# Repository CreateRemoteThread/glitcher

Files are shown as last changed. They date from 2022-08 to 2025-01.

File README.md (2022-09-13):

# glitcher

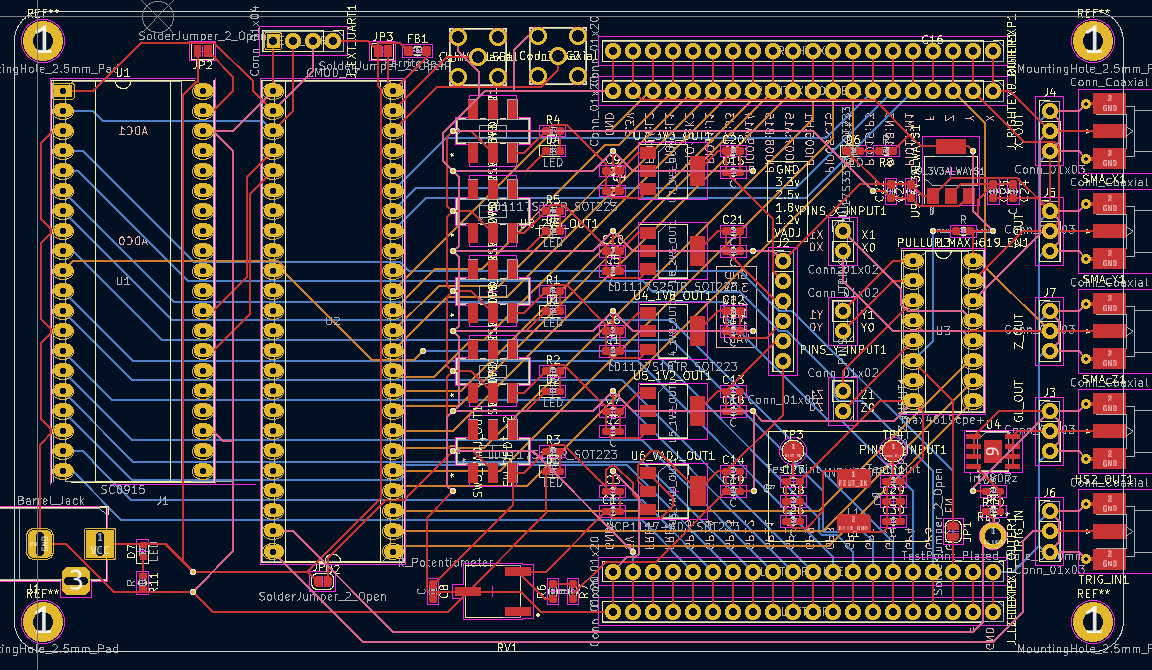
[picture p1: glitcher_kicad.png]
Glitcher Schematic


## Introduction

Glitcher is a homebrew fault injection system, built around a Pi Pico and CMOD A7, with a MAX4619 and an irf7807 providing multiplexer and crowbar mosfet style glitching respectively. Generous GPIO (FPGA + Pi Pico) + SMA outputs are available.

This project is heavily inspired by the ChipWhisperer set of products.

## Use

The Pi Pico is the simplest method of using this. Using a micro USB cable, access the MicroPython interface and use the glitcher library to control the FPGA's default firmware:

```
import glitcher

g = glitcher.Glitcher()
g.enablemux(True)                # enable max4619. crowbar always "on"
g.setmask(glitcher.SELECT_MOSFET)         # select mosfet for glitching
g.muxout(glitcher.SELECT_MUXA)            # switch x_out to x1
g.muxout(glitcher.SELECT_NONE)            # switch x_out to x0
g.rnr(delay=5,width=5)           # write delay/width, glitch output according to setmask
```

The Pi Pico uses only a serial port to talk to the FPGA at 115200bps, so you can swap it for some other uC / make a shield / whatever. Just replace self.u1 with a pyserial output if you want to use a control PC (enablemux is the only thing requiring the pi pico, just hardwire it idk).

Probably don't use g.muxout(0xF) - but do whatever you want.

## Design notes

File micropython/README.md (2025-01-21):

# Notes

Glitcher is primarily used via the MicroPython interface on the Raspberry Pi Pico. This allows for a number of things to be initialized without 

## AVR Glitcher

```import glitcher
import avr
import time

a = avr.AVRTarget()
g = glitcher.Glitcher()
g.setmask(glitcher.SELECT_MOSFET)
g.enablemux(1)
resetter = Pin(6,Pin.OUT)
resetter.value(1)

for i in range(110,130):
    if i % 5 == 0:
        print(i)
    for x in range(1,5):
        de = i
        g.setrepeat(num=2,delay=9)
        g.rnr(delay=de,width=7)
        f = a.fire()
        if f != b'62500\r\n':
            print("%d:%s" % (de,f))
            resetter.value(0)
            time.sleep(0.5)
            resetter.value(1)
            time.sleep(0.1)
            a.u1.read()
        time.sleep(0.2)```

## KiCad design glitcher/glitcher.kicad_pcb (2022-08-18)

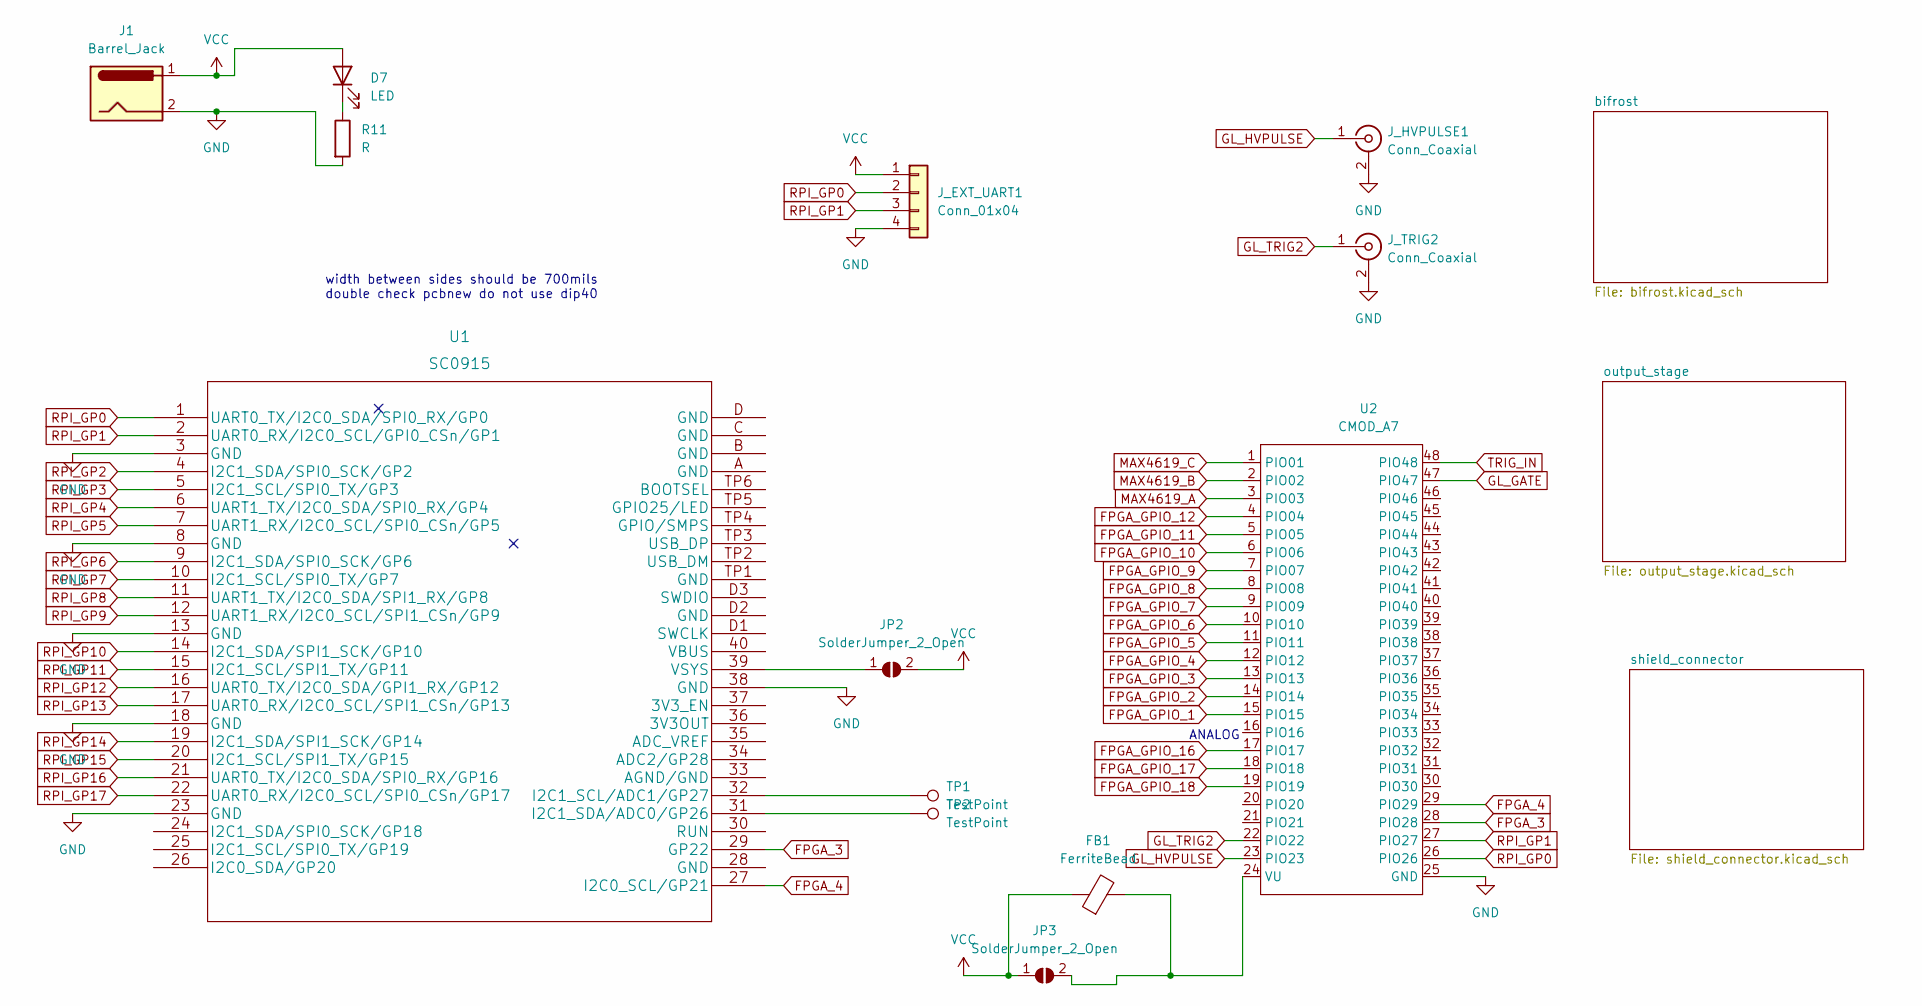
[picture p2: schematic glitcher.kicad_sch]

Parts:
D7: LED; LED_0603_1608Metric
FB1: FerriteBead; L_0805_2012Metric_Pad1.05x1.20mm_HandSolder
J1: Barrel_Jack; BarrelJack_Horizontal
JP2, JP3: SolderJumper_2_Open; SolderJumper-2_P1.3mm_Open_Pad1.0x1.5mm
J_EXT_UART1: Conn_01x04; PinHeader_1x04_P2.54mm_Vertical
J_HVPULSE1: Conn_Coaxial; RF2-04A-T-00-50-G
J_TRIG2: Conn_Coaxial; RF2-04A-T-00-50-G
R11: R; R_0603_1608Metric
TP1, TP2: TestPoint; TestPoint_Pad_D3.0mm
U1: SC0915; rpi_socket_fixed
U2: CMOD_A7; DIP-48_W15.24mm_Socket_LongPads

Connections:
FPGA_3: U1.29 (GP22), U2.28 (PIO28)
FPGA_4: U1.27 (I2C0_SCL/GP21), U2.29 (PIO29)
FPGA_GPIO_1: U2.15 (PIO15)
FPGA_GPIO_2: U2.14 (PIO14); also elsewhere on the board
FPGA_GPIO_3: U2.13 (PIO13); also elsewhere on the board
FPGA_GPIO_4: U2.12 (PIO12); also elsewhere on the board
FPGA_GPIO_5: U2.11 (PIO11); also elsewhere on the board
FPGA_GPIO_6: U2.10 (PIO10); also elsewhere on the board
FPGA_GPIO_7: U2.9 (PIO09); also elsewhere on the board
FPGA_GPIO_8: U2.8 (PIO08); also elsewhere on the board
FPGA_GPIO_9: U2.7 (PIO07); also elsewhere on the board
FPGA_GPIO_10: U2.6 (PIO06); also elsewhere on the board
FPGA_GPIO_11: U2.5 (PIO05); also elsewhere on the board
FPGA_GPIO_12: U2.4 (PIO04); also elsewhere on the board
FPGA_GPIO_16: U2.17 (PIO17); also elsewhere on the board
FPGA_GPIO_17: U2.18 (PIO18); also elsewhere on the board
FPGA_GPIO_18: U2.19 (PIO19); also elsewhere on the board
GL_GATE: U2.47 (PIO47); also elsewhere on the board
GL_HVPULSE: J_HVPULSE1.1 (In), U2.23 (PIO23)
GL_TRIG2: J_TRIG2.1 (In), U2.22 (PIO22)
GND: J1.2, J_EXT_UART1.4, J_HVPULSE1.2 (Ext), J_HVPULSE1.3, J_HVPULSE1.4, J_HVPULSE1.5, J_TRIG2.2 (Ext), J_TRIG2.3, J_TRIG2.4, J_TRIG2.5, R11.2, U1.3 (GND), U1.8 (GND), U1.13 (GND), U1.18 (GND), U1.23 (GND), U1.38 (GND), U2.25 (GND); also elsewhere on the board
MAX4619_A: U2.3 (PIO03); also elsewhere on the board
MAX4619_B: U2.2 (PIO02); also elsewhere on the board
MAX4619_C: U2.1 (PIO01); also elsewhere on the board
unnamed: D7.1 (K), R11.1
unnamed: FB1.2, JP3.2 (B), U2.24 (VU)
unnamed: JP2.1 (A), U1.39 (VSYS)
unnamed: TP1.1, U1.32 (I2C1_SCL/ADC1/GP27)
unnamed: TP2.1, U1.31 (I2C1_SDA/ADC0/GP26)
RPI_GP0: J_EXT_UART1.2, U1.1 (UART0_TX/I2C0_SDA/SPI0_RX/GP0), U2.26 (PIO26)
RPI_GP1: J_EXT_UART1.3, U1.2 (UART0_RX/I2C0_SCL/GPI0_CSn/GP1), U2.27 (PIO27)
RPI_GP2: U1.4 (I2C1_SDA/SPI0_SCK/GP2); also elsewhere on the board
RPI_GP3: U1.5 (I2C1_SCL/SPI0_TX/GP3); also elsewhere on the board
RPI_GP4: U1.6 (UART1_TX/I2C0_SDA/SPI0_RX/GP4); also elsewhere on the board
RPI_GP5: U1.7 (UART1_RX/I2C0_SCL/SPI0_CSn/GP5); also elsewhere on the board
RPI_GP6: U1.9 (I2C1_SDA/SPI0_SCK/GP6); also elsewhere on the board
RPI_GP7: U1.10 (I2C1_SCL/SPI0_TX/GP7); also elsewhere on the board
RPI_GP8: U1.11 (UART1_TX/I2C0_SDA/SPI1_RX/GP8); also elsewhere on the board
RPI_GP9: U1.12 (UART1_RX/I2C0_SCL/SPI1_CSn/GP9); also elsewhere on the board
RPI_GP10: U1.14 (I2C1_SDA/SPI1_SCK/GP10); also elsewhere on the board
RPI_GP11: U1.15 (I2C1_SCL/SPI1_TX/GP11); also elsewhere on the board
RPI_GP12: U1.16 (UART0_TX/I2C0_SDA/GPI1_RX/GP12); also elsewhere on the board
RPI_GP13: U1.17 (UART0_RX/I2C0_SCL/SPI1_CSn/GP13); also elsewhere on the board
RPI_GP14: U1.19 (I2C1_SDA/SPI1_SCK/GP14); also elsewhere on the board
RPI_GP15: U1.20 (I2C1_SCL/SPI1_TX/GP15); also elsewhere on the board
RPI_GP16: U1.21 (UART0_TX/I2C0_SDA/SPI0_RX/GP16)
RPI_GP17: U1.22 (UART0_RX/I2C0_SCL/SPI0_CSn/GP17)
TRIG_IN: U2.48 (PIO48); also elsewhere on the board
VCC: D7.2 (A), FB1.1, J1.1, JP2.2 (B), JP3.1 (A), J_EXT_UART1.1; also elsewhere on the board

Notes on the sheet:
width between sides should be 700mils double check pcbnew do not use dip40
ANALOG

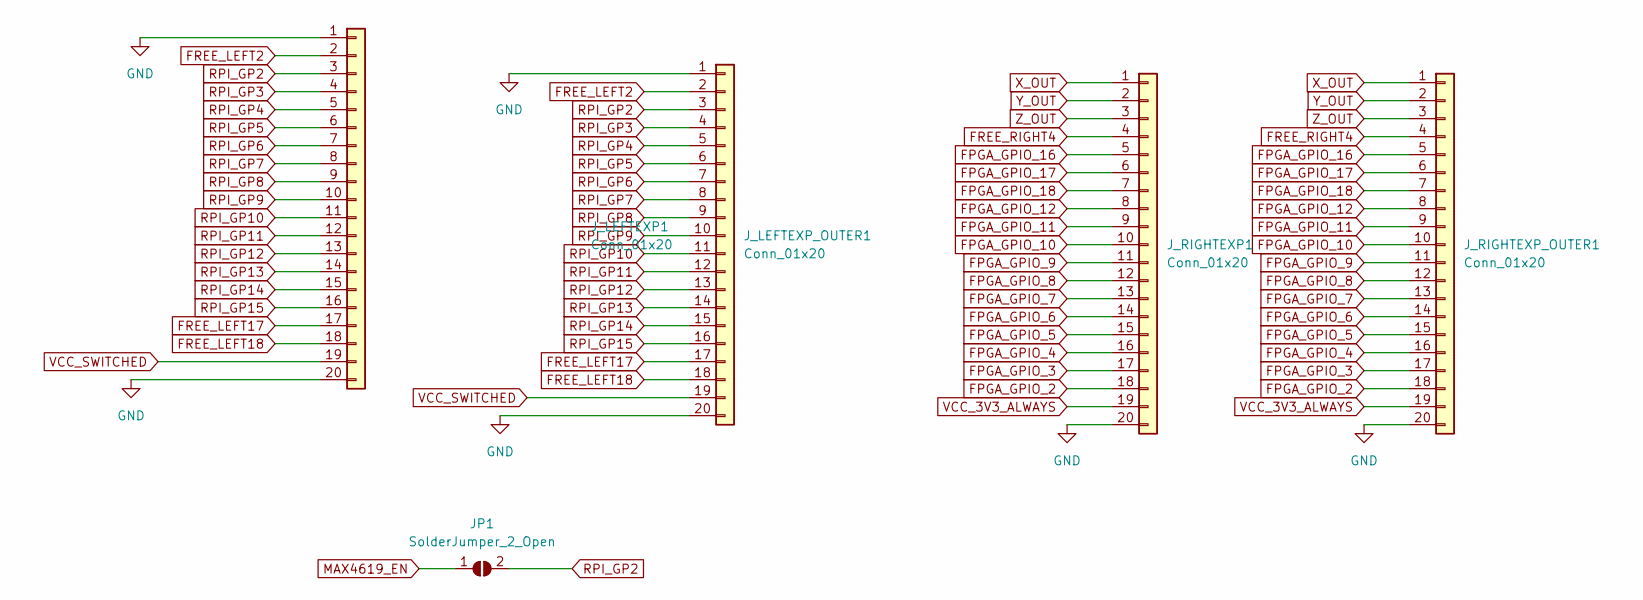
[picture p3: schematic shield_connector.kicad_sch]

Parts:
JP1: SolderJumper_2_Open; SolderJumper-2_P1.3mm_Open_RoundedPad1.0x1.5mm
J_LEFTEXP1: Conn_01x20; PinHeader_1x20_P2.54mm_Vertical
J_LEFTEXP_OUTER1: Conn_01x20; PinHeader_1x20_P2.54mm_Vertical
J_RIGHTEXP1: Conn_01x20; PinHeader_1x20_P2.54mm_Vertical
J_RIGHTEXP_OUTER1: Conn_01x20; PinHeader_1x20_P2.54mm_Vertical

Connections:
FPGA_GPIO_2: J_RIGHTEXP1.18, J_RIGHTEXP_OUTER1.18; also elsewhere on the board
FPGA_GPIO_3: J_RIGHTEXP1.17, J_RIGHTEXP_OUTER1.17; also elsewhere on the board
FPGA_GPIO_4: J_RIGHTEXP1.16, J_RIGHTEXP_OUTER1.16; also elsewhere on the board
FPGA_GPIO_5: J_RIGHTEXP1.15, J_RIGHTEXP_OUTER1.15; also elsewhere on the board
FPGA_GPIO_6: J_RIGHTEXP1.14, J_RIGHTEXP_OUTER1.14; also elsewhere on the board
FPGA_GPIO_7: J_RIGHTEXP1.13, J_RIGHTEXP_OUTER1.13; also elsewhere on the board
FPGA_GPIO_8: J_RIGHTEXP1.12, J_RIGHTEXP_OUTER1.12; also elsewhere on the board
FPGA_GPIO_9: J_RIGHTEXP1.11, J_RIGHTEXP_OUTER1.11; also elsewhere on the board
FPGA_GPIO_10: J_RIGHTEXP1.10, J_RIGHTEXP_OUTER1.10; also elsewhere on the board
FPGA_GPIO_11: J_RIGHTEXP1.9, J_RIGHTEXP_OUTER1.9; also elsewhere on the board
FPGA_GPIO_12: J_RIGHTEXP1.8, J_RIGHTEXP_OUTER1.8; also elsewhere on the board
FPGA_GPIO_16: J_RIGHTEXP1.5, J_RIGHTEXP_OUTER1.5; also elsewhere on the board
FPGA_GPIO_17: J_RIGHTEXP1.6, J_RIGHTEXP_OUTER1.6; also elsewhere on the board
FPGA_GPIO_18: J_RIGHTEXP1.7, J_RIGHTEXP_OUTER1.7; also elsewhere on the board
FREE_LEFT2: J_LEFTEXP1.2, J_LEFTEXP_OUTER1.2
FREE_LEFT17: J_LEFTEXP1.17, J_LEFTEXP_OUTER1.17
FREE_LEFT18: J_LEFTEXP1.18, J_LEFTEXP_OUTER1.18
FREE_RIGHT4: J_RIGHTEXP1.4, J_RIGHTEXP_OUTER1.4
GND: J_LEFTEXP1.1, J_LEFTEXP1.20, J_LEFTEXP_OUTER1.1, J_LEFTEXP_OUTER1.20, J_RIGHTEXP1.20, J_RIGHTEXP_OUTER1.20; also elsewhere on the board
MAX4619_EN: JP1.1 (A); also elsewhere on the board
RPI_GP2: JP1.2 (B), J_LEFTEXP1.3, J_LEFTEXP_OUTER1.3; also elsewhere on the board
RPI_GP3: J_LEFTEXP1.4, J_LEFTEXP_OUTER1.4; also elsewhere on the board
RPI_GP4: J_LEFTEXP1.5, J_LEFTEXP_OUTER1.5; also elsewhere on the board
RPI_GP5: J_LEFTEXP1.6, J_LEFTEXP_OUTER1.6; also elsewhere on the board
RPI_GP6: J_LEFTEXP1.7, J_LEFTEXP_OUTER1.7; also elsewhere on the board
RPI_GP7: J_LEFTEXP1.8, J_LEFTEXP_OUTER1.8; also elsewhere on the board
RPI_GP8: J_LEFTEXP1.9, J_LEFTEXP_OUTER1.9; also elsewhere on the board
RPI_GP9: J_LEFTEXP1.10, J_LEFTEXP_OUTER1.10; also elsewhere on the board
RPI_GP10: J_LEFTEXP1.11, J_LEFTEXP_OUTER1.11; also elsewhere on the board
RPI_GP11: J_LEFTEXP1.12, J_LEFTEXP_OUTER1.12; also elsewhere on the board
RPI_GP12: J_LEFTEXP1.13, J_LEFTEXP_OUTER1.13; also elsewhere on the board
RPI_GP13: J_LEFTEXP1.14, J_LEFTEXP_OUTER1.14; also elsewhere on the board
RPI_GP14: J_LEFTEXP1.15, J_LEFTEXP_OUTER1.15; also elsewhere on the board
RPI_GP15: J_LEFTEXP1.16, J_LEFTEXP_OUTER1.16; also elsewhere on the board
VCC_3V3_ALWAYS: J_RIGHTEXP1.19, J_RIGHTEXP_OUTER1.19; also elsewhere on the board
VCC_SWITCHED: J_LEFTEXP1.19, J_LEFTEXP_OUTER1.19; also elsewhere on the board
X_OUT: J_RIGHTEXP1.1, J_RIGHTEXP_OUTER1.1; also elsewhere on the board
Y_OUT: J_RIGHTEXP1.2, J_RIGHTEXP_OUTER1.2; also elsewhere on the board
Z_OUT: J_RIGHTEXP1.3, J_RIGHTEXP_OUTER1.3; also elsewhere on the board

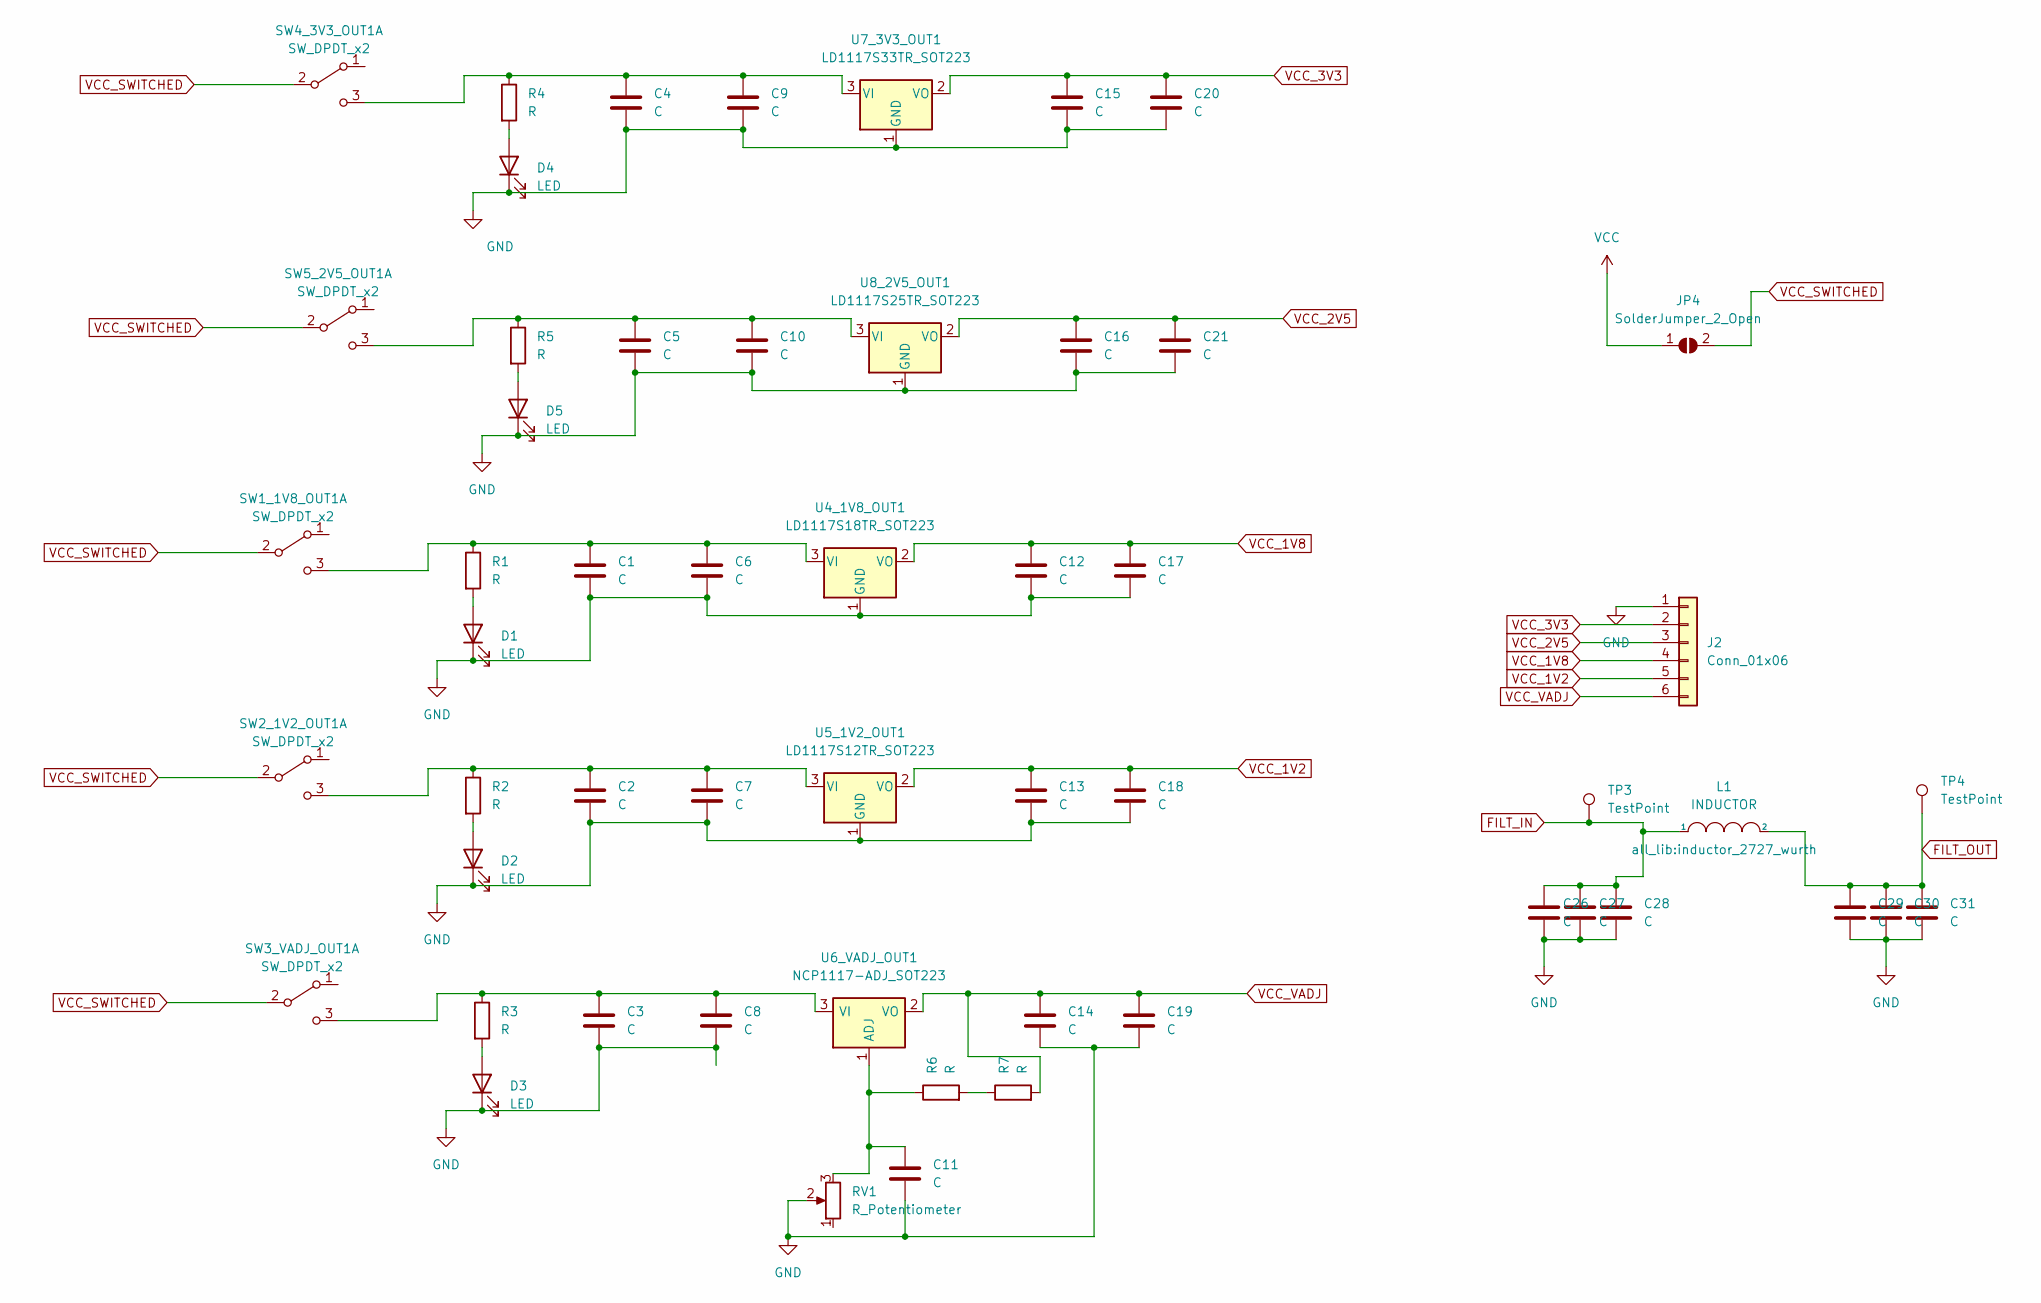
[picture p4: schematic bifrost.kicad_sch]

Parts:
C1, C2, C3, C4, C5, C6, C7, C8, C9, C10, C11, C12, C13, C14, C15, C16, C17, C18, C19, C20, C21, C26, C27, C28, C29, C30, C31: C; C_0603_1608Metric_Pad1.08x0.95mm_HandSolder
D1, D2, D3, D4, D5: LED; LED_0603_1608Metric_Pad1.05x0.95mm_HandSolder
J2: Conn_01x06; PinHeader_1x06_P2.54mm_Vertical
JP4: SolderJumper_2_Open; SolderJumper-2_P1.3mm_Open_RoundedPad1.0x1.5mm
L1: INDUCTOR; inductor_2727_wurth
R1, R2, R3, R4, R5, R6, R7: R; R_0603_1608Metric_Pad0.98x0.95mm_HandSolder
RV1: R_Potentiometer; TRIM_3361P-1-501GLF
SW1_1V8_OUT1, SW2_1V2_OUT1, SW3_VADJ_OUT1, SW4_3V3_OUT1, SW5_2V5_OUT1: SW_DPDT_x2; JS202011SCQN
TP3, TP4: TestPoint; TestPoint_Pad_D2.5mm
U4_1V8_OUT1: LD1117S18TR_SOT223; SOT-223-3_TabPin2
U5_1V2_OUT1: LD1117S12TR_SOT223; SOT-223-3_TabPin2
U6_VADJ_OUT1: NCP1117-ADJ_SOT223; SOT-223-3_TabPin2
U7_3V3_OUT1: LD1117S33TR_SOT223; SOT-223-3_TabPin2
U8_2V5_OUT1: LD1117S25TR_SOT223; SOT-223-3_TabPin2

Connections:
FILT_IN: C26.1, C27.1, C28.1, L1.1, TP3.1
FILT_OUT: C29.1, C30.1, C31.1, L1.2, TP4.1
GND: C1.2, C2.2, C3.2, C4.2, C5.2, C6.2, C7.2, C8.2, C9.2, C10.2, C11.2, C12.2, C13.2, C14.2, C15.2, C16.2, C17.2, C18.2, C19.2, C20.2, C21.2, C26.2, C27.2, C28.2, C29.2, C30.2, C31.2, D1.1 (K), D2.1 (K), D3.1 (K), D4.1 (K), D5.1 (K), J2.1, RV1.2, U4_1V8_OUT1.1 (GND), U5_1V2_OUT1.1 (GND), U7_3V3_OUT1.1 (GND), U8_2V5_OUT1.1 (GND); also elsewhere on the board
unnamed: C1.1, C6.1, R1.1, SW1_1V8_OUT1.3 (C), U4_1V8_OUT1.3 (VI)
unnamed: C2.1, C7.1, R2.1, SW2_1V2_OUT1.3 (C), U5_1V2_OUT1.3 (VI)
unnamed: C3.1, C8.1, R3.1, SW3_VADJ_OUT1.3 (C), U6_VADJ_OUT1.3 (VI)
unnamed: C4.1, C9.1, R4.1, SW4_3V3_OUT1.3 (C), U7_3V3_OUT1.3 (VI)
unnamed: C5.1, C10.1, R5.1, SW5_2V5_OUT1.3 (C), U8_2V5_OUT1.3 (VI)
unnamed: C11.1, R6.1, RV1.3, U6_VADJ_OUT1.1 (ADJ)
unnamed: D1.2 (A), R1.2
unnamed: D2.2 (A), R2.2
unnamed: D3.2 (A), R3.2
unnamed: D4.2 (A), R4.2
unnamed: D5.2 (A), R5.2
unnamed: R6.2, R7.1
VCC: JP4.1 (A); also elsewhere on the board
VCC_1V2: C13.1, C18.1, J2.5, U5_1V2_OUT1.2 (VO)
VCC_1V8: C12.1, C17.1, J2.4, U4_1V8_OUT1.2 (VO)
VCC_2V5: C16.1, C21.1, J2.3, U8_2V5_OUT1.2 (VO)
VCC_3V3: C15.1, C20.1, J2.2, U7_3V3_OUT1.2 (VO)
VCC_SWITCHED: JP4.2 (B), SW1_1V8_OUT1.2 (B), SW2_1V2_OUT1.2 (B), SW3_VADJ_OUT1.2 (B), SW4_3V3_OUT1.2 (B), SW5_2V5_OUT1.2 (B); also elsewhere on the board
VCC_VADJ: C14.1, C19.1, J2.6, R7.2, U6_VADJ_OUT1.2 (VO)

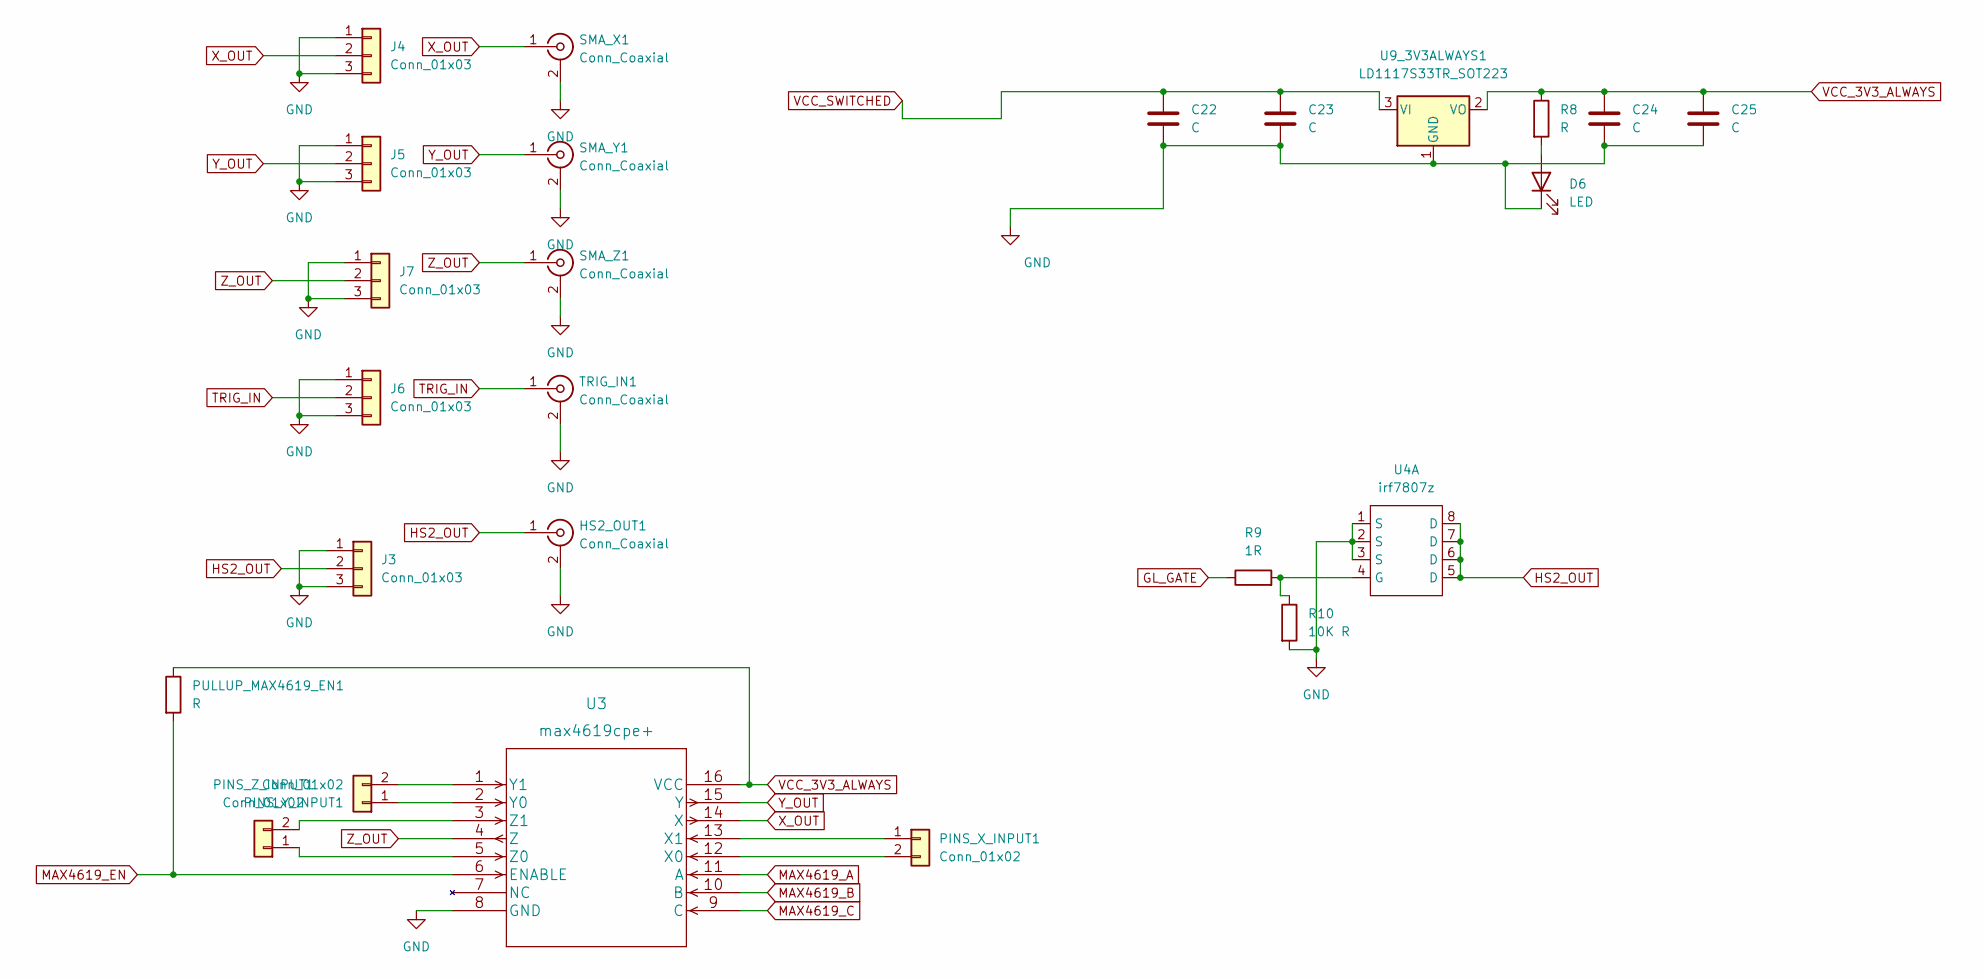
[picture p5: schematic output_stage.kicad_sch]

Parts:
C22, C23, C24, C25: C; C_0603_1608Metric_Pad1.08x0.95mm_HandSolder
D6: LED; LED_0603_1608Metric_Pad1.05x0.95mm_HandSolder
HS2_OUT1: Conn_Coaxial; SMA_Molex_73251-2120_EdgeMount_Horizontal
J3, J4, J5, J6, J7: Conn_01x03; PinHeader_1x03_P2.54mm_Vertical
PINS_X_INPUT1: Conn_01x02; PinHeader_1x02_P2.54mm_Vertical
PINS_Y_INPUT1: Conn_01x02; PinHeader_1x02_P2.54mm_Vertical
PINS_Z_INPUT1: Conn_01x02; PinHeader_1x02_P2.54mm_Vertical
PULLUP_MAX4619_EN1: R; R_0603_1608Metric_Pad0.98x0.95mm_HandSolder
R8: R; R_0603_1608Metric_Pad0.98x0.95mm_HandSolder
R9: 1R; R_0603_1608Metric_Pad0.98x0.95mm_HandSolder
R10: 10K R; R_0603_1608Metric_Pad0.98x0.95mm_HandSolder
SMA_X1: Conn_Coaxial; SMA_Molex_73251-2120_EdgeMount_Horizontal
SMA_Y1: Conn_Coaxial; SMA_Molex_73251-2120_EdgeMount_Horizontal
SMA_Z1: Conn_Coaxial; SMA_Molex_73251-2120_EdgeMount_Horizontal
TRIG_IN1: Conn_Coaxial; SMA_Molex_73251-2120_EdgeMount_Horizontal
U3: max4619cpe+; DIP-16_W7.62mm_Socket_LongPads
U4: irf7807z; SOIC-8-1EP_3.9x4.9mm_P1.27mm_EP2.29x3mm
U9_3V3ALWAYS1: LD1117S33TR_SOT223; SOT-223-3_TabPin2

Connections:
GL_GATE: R9.1; also elsewhere on the board
GND: C22.2, C23.2, C24.2, C25.2, D6.1 (K), HS2_OUT1.2 (Ext), J3.1, J3.3, J4.1, J4.3, J5.1, J5.3, J6.1, J6.3, J7.1, J7.3, R10.2, SMA_X1.2 (Ext), SMA_Y1.2 (Ext), SMA_Z1.2 (Ext), TRIG_IN1.2 (Ext), U3.8 (GND), U4.1 (S), U4.2 (S), U4.3 (S), U9_3V3ALWAYS1.1 (GND); also elsewhere on the board
HS2_OUT: HS2_OUT1.1 (In), J3.2, U4.5 (D), U4.6 (D), U4.7 (D), U4.8 (D)
MAX4619_A: U3.11 (A); also elsewhere on the board
MAX4619_B: U3.10 (B); also elsewhere on the board
MAX4619_C: U3.9 (C); also elsewhere on the board
MAX4619_EN: PULLUP_MAX4619_EN1.2, U3.6 (ENABLE); also elsewhere on the board
unnamed: D6.2 (A), R8.2
unnamed: PINS_X_INPUT1.1, U3.13 (X1)
unnamed: PINS_X_INPUT1.2, U3.12 (X0)
unnamed: PINS_Y_INPUT1.1, U3.2 (Y0)
unnamed: PINS_Y_INPUT1.2, U3.1 (Y1)
unnamed: PINS_Z_INPUT1.1, U3.5 (Z0)
unnamed: PINS_Z_INPUT1.2, U3.3 (Z1)
unnamed: R9.2, R10.1, U4.4 (G)
TRIG_IN: J6.2, TRIG_IN1.1 (In); also elsewhere on the board
VCC_3V3_ALWAYS: C24.1, C25.1, PULLUP_MAX4619_EN1.1, R8.1, U3.16 (VCC), U9_3V3ALWAYS1.2 (VO); also elsewhere on the board
VCC_SWITCHED: C22.1, C23.1, U9_3V3ALWAYS1.3 (VI); also elsewhere on the board
X_OUT: J4.2, SMA_X1.1 (In), U3.14 (X); also elsewhere on the board
Y_OUT: J5.2, SMA_Y1.1 (In), U3.15 (Y); also elsewhere on the board
Z_OUT: J7.2, SMA_Z1.1 (In), U3.4 (Z); also elsewhere on the board

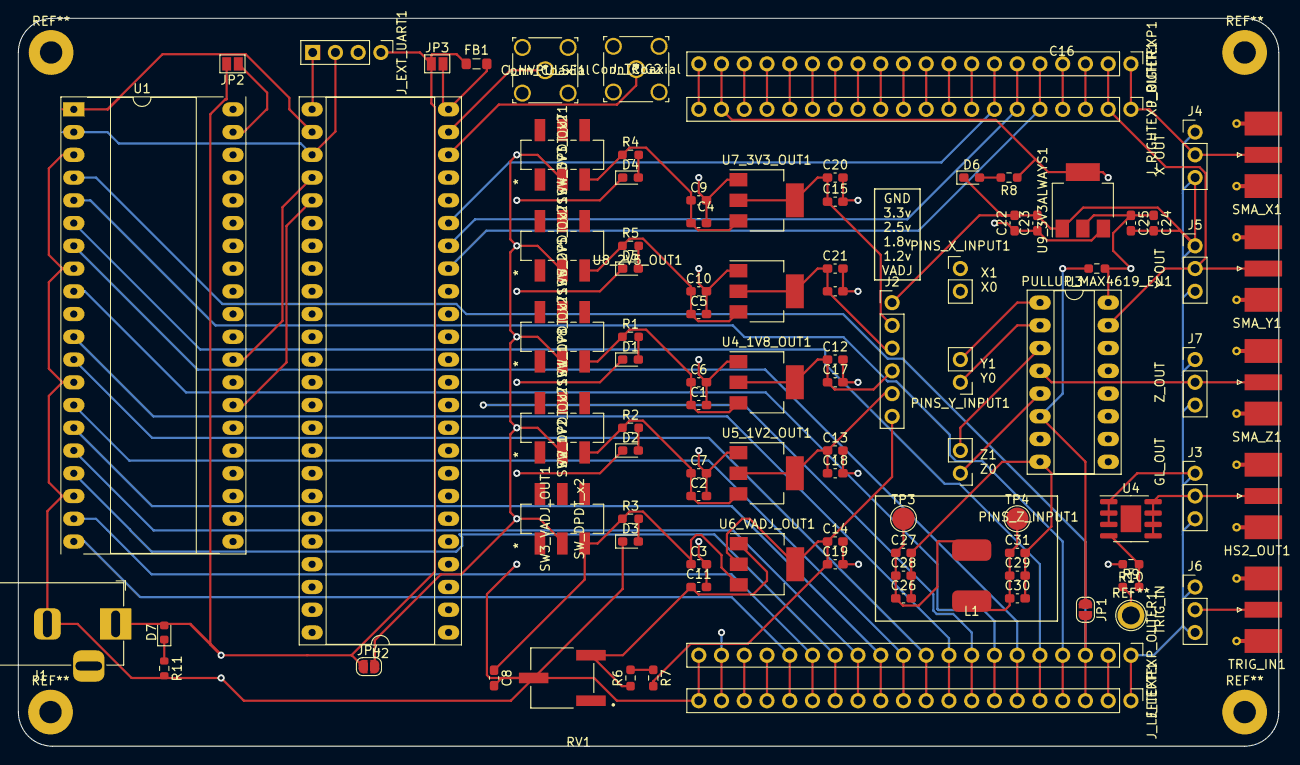
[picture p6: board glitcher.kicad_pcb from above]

Board: 6 copper layers, 140.8 x 81.3 mm, 96 parts (0 on the bottom side), 82 nets.

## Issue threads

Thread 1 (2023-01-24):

AVR Stuff

CreateRemoteThread, 2023-01-24:
- avr.AVRProgrammer() does not seem to be able to "re-use" a session (e.g. after releasing CS and starting again). Seems to work if we recreate the SPI peripheral (i.e. move __init__ to enterProgramming).
- fillMemory is busted, and doesn't allow a nice way to feed a bin file from disk (particularly within rshell).
- Currently using the NewAE advanced breakout board, but MISO works inconsistently.
  - Opportunity to make custom level shfiter with programmable output for automation. (+ SPI "stacking" / passthrough???)

Closed 2023-03-26.

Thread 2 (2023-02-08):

HW+FPGA Notes

CreateRemoteThread, 2023-02-08:
Todo:
- Convert UART IO to register map (currently: cfgreg1)
- Clock manip (new rev?)
- Relabel aux outputs at top of board
- Label male header pins at border
- 3x output -> 2x output (both VADJ?)

Done:
- Invert trigger option

CreateRemoteThread, 2023-02-08:
Falling edge trigger has incorrect logic (never fires). Unsure if problem is input or output stage (mosfet out).
stlinkv2 test case.

CreateRemoteThread, 2023-04-02:
Faceplate:
- Status LED's
- Onboard ADC?
- PCIe target connector?
- Considerations for EM?

todo buy a new heat gun thingy

Closed 2025-01-18.

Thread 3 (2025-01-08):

2025 updates list

CreateRemoteThread, 2025-01-08:
- double sided shield v3 with leds
- integrated usb fuzzer (with glitcher)
- double battery trick
- new power connector
- change multiplexer to soic/dip converter (and hook up muxc default)

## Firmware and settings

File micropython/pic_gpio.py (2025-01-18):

from machine import Pin
import glitcher
from time import sleep, sleep_ms, sleep_us, ticks_ms
import random
from rp2 import PIO,StateMachine,asm_pio

# pio method turned out to be a huge fuckaround, so using this instead:
# https://github.com/SyedTahmidMahbub/q-dpico_picprog72/blob/main/prog72.py
# This is for pic16f1788 with the mchp key and xbit, check before you re-use

MCLR_PIN = 13
PGD_PIN  = 14
PGC_PIN  = 15

INVERTER_IN = 6
INVERTER_OUT = 12

# simpleInverter: x is the delay, y is pulse duration
@asm_pio(set_init=[PIO.OUT_LOW])
def simpleInverter():
    wrap_target()
    pull()
    mov(x,osr)
    pull()
    mov(y,osr)
    wait(0,pin,0)
    label("loop_wait")
    jmp(x_dec,"loop_wait")
    set(pins,1)
    label("loop_pulse")
    jmp(y_dec,"loop_pulse")
    set(pins,0)
    wrap()

DELAY_X = 30
PULSE_Y = 15

pin_in = Pin(INVERTER_IN, Pin.IN)
pin_set = Pin(INVERTER_OUT)
sm = StateMachine(0,simpleInverter,freq=40000000,in_base=pin_in, set_base=pin_set,pull_thresh=32)

# sm.active(1)

@micropython.asm_thumb
def tsethold():
    nop()
    nop()
    nop()
    nop()
    nop()
    nop()
    nop()
    nop()
    nop()
    nop()
    nop()
    nop()
    nop()

class PICProgrammer:
    def __init__(self):
        self.PGD = Pin(PGD_PIN, Pin.IN)
        self.PGC = Pin(PGC_PIN, Pin.IN)
        self.MCLR = Pin(MCLR_PIN, Pin.OUT, value=1)

    def enterPrg(self):
        self.MCLR.value(0)
        self.PGD.init(self.PGD.OUT,value=0)
        self.PGC.init(self.PGC.OUT,value=0)
        sleep_us(1)
    def exitPrg(self):
        self.PGD.init(self.PGD.IN)
        self.PGC.init(self.PGC.IN)
        self.MCLR.value(1)
    
    def erase(self,addr=None,sm_trigger=True):
        if addr is None:
            self.command(0x00)
            self.write_data(0x3FFF)
        else:
            self.command(0x16)
            for i in range(0,addr):
                self.command(0x06)
                sleep_us(5)
            # self.write_data(0x3FFF)
        self.command(0x09,sm_trigger=sm_trigger)
    
    def cfgRead(self):
        self.command(0x00)
        self.write_data(0x0004)
        for i in range(0,7):
            self.command(0x06)
        self.command(0x04)
        print("cfg read")
        print(hex(self.read_data()))
    
    def cfgLock(self,payload=None):
        self.command(0x00)
        if payload is None:
            self.write_data(0x0004)
        else:
            self.write_data(payload)
        for i in range(0,7):
            self.command(0x06)
        self.command(0x08)

    def cfgUnlock(self):
        self.command(0x00)
        self.write_data(0x0180)
        for i in range(0,7):
            self.command(0x06)
        self.command(0x08)
          
    def xbit(self):
        self.PGC.value(1)
        self.PGD.value(0)
        tsethold()
        self.PGC.value(0)
        tsethold()
        
    def sendKey(self):
        out_stream = ""
        ICSP_STARTUP_KEY = [0b1001101,0b1000011,0b1001000,0b1010000]
        for x in range(3,-1,-1):
            key_byte = ICSP_STARTUP_KEY[x]
            for y in range(0,8):
                self.PGC.value(1)
                b = (key_byte >> y) & 1
                self.PGD.value(b)
                tsethold()
                self.PGC.value(0)
                tsethold()
        self.xbit()

    def setParams(self,delay=65700,pulse=4000):
        self.delay = delay
        self.pulse = pulse
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

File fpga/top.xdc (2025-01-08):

# set_property PACKAGE_PIN C15 [get_ports i_uart_rx]
# set_property PACKAGE_PIN H1 [get_ports o_uart_tx]

set_property PACKAGE_PIN R3 [get_ports i_uart_rx]
set_property PACKAGE_PIN T3 [get_ports o_uart_tx]
set_property PACKAGE_PIN A16 [get_ports o_max4619_a]
set_property PACKAGE_PIN L3 [get_ports o_max4619_b]
set_property PACKAGE_PIN M3 [get_ports o_max4619_c]

# set_property PACKAGE_PIN B15 [get_ports o_glitch]
set_property PACKAGE_PIN U8 [get_ports o_glitch]
# set_property PACKAGE_PIN K3 [get_ports i_trig]
set_property PACKAGE_PIN V8 [get_ports i_trig]


set_property PACKAGE_PIN C17 [get_ports rgb_led_r]
set_property PACKAGE_PIN B16 [get_ports rgb_led_g]
set_property PACKAGE_PIN B17 [get_ports rgb_led_b]

set_property PACKAGE_PIN R2 [get_ports i_fpga3]
set_property PACKAGE_PIN T1 [get_ports i_fpga4]
set_property IOSTANDARD LVCMOS33 [get_ports i_fpga3]
set_property IOSTANDARD LVCMOS33 [get_ports i_fpga4]
set_property IOSTANDARD LVCMOS33 [get_ports i_uart_rx]

set_property IOSTANDARD LVCMOS33 [get_ports o_glitch]
set_property IOSTANDARD LVCMOS33 [get_ports i_trig]

set_property IOSTANDARD LVCMOS33 [get_ports rgb_led_r]
set_property IOSTANDARD LVCMOS33 [get_ports rgb_led_g]
set_property IOSTANDARD LVCMOS33 [get_ports rgb_led_b]

set_property IOSTANDARD LVCMOS33 [get_ports o_max4619_a]
set_property IOSTANDARD LVCMOS33 [get_ports o_max4619_b]
set_property IOSTANDARD LVCMOS33 [get_ports o_max4619_c]
set_property IOSTANDARD LVCMOS33 [get_ports o_uart_tx]
set_property IOSTANDARD LVCMOS33 [get_ports test_led]

set_property PACKAGE_PIN M1 [get_ports o_m1]
set_property PACKAGE_PIN N3 [get_ports o_n3]
set_property PACKAGE_PIN P3 [get_ports o_p3]

set_property IOSTANDARD LVCMOS33 [get_ports o_m1]
set_property IOSTANDARD LVCMOS33 [get_ports o_n3]
set_property IOSTANDARD LVCMOS33 [get_ports o_p3]

set_property PACKAGE_PIN P1 [get_ports o_auxout]
set_property PACKAGE_PIN N2 [get_ports o_clkout]
set_property IOSTANDARD LVCMOS33 [get_ports o_auxout]
set_property IOSTANDARD LVCMOS33 [get_ports o_clkout]

set_property PACKAGE_PIN A17 [get_ports test_led]

set_property SLEW FAST [get_ports o_glitch]
set_property DRIVE 12 [get_ports o_glitch]


set_property PACKAGE_PIN L2 [get_ports i_wforce]
set_property IOSTANDARD LVCMOS33 [get_ports i_wforce]

set_property IOSTANDARD LVCMOS18 [get_ports i_sysclk]
set_property OFFCHIP_TERM NONE [get_ports test_led]
set_property PACKAGE_PIN L17 [get_ports i_sysclk]

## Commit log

2022-09-03 workbench shield thingy
    [shield-B_Cu.gbr, shield-B_Mask.gbr, shield-B_Paste.gbr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]
2022-09-07 protoboard shield
    [shield_holes-B_Cu.gbr, shield_holes-B_Mask.gbr, shield_holes-B_Paste.gbr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]
2022-09-13 implemented g.muxout, python fixes
    [command.v, glitcher.py]
2023-02-07 py workaround for mistake - muxc <-> muxb
    [glitcher.py]
2023-02-08 verilog / py fixes for param edgetgt
    [command.v, glitcher.py]
2025-01-03 fix: xbit on send mchp key
    [pic_gpio.py]

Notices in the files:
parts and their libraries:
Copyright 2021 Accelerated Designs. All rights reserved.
